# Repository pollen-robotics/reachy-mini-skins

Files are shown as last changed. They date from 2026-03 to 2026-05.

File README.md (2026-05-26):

# 🎨 Reachy Mini Skins

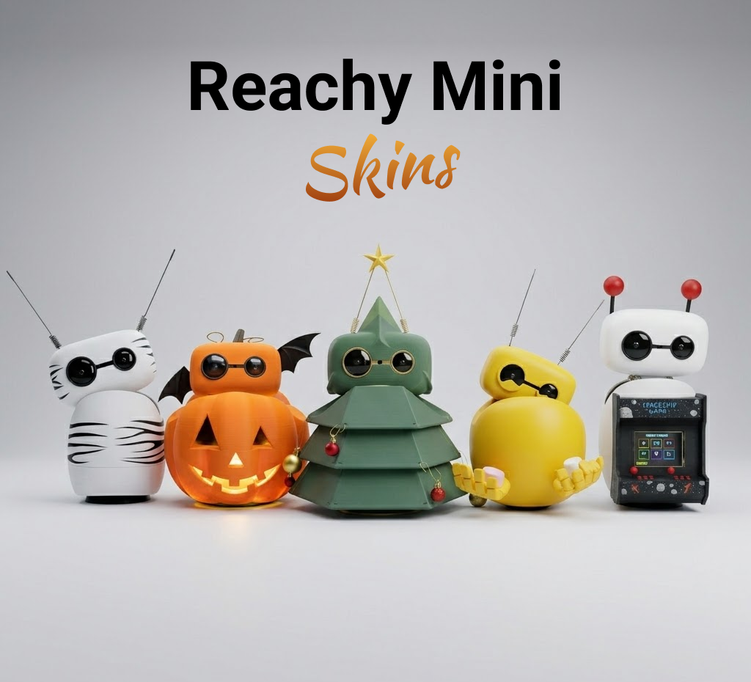
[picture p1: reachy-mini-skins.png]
reachy-mini-skins


This repository gathers the official Reachy Mini skins created by Pollen Robotics, showcasing playful, seasonal, refined, and expressive ways to bring personality to your robot.

From playful and seasonal designs to more refined and expressive looks, these official skins showcase different ways to bring personality to Reachy Mini.

Community creations are not included in this repository. They are available on the [Reachy Mini Skins Space](https://huggingface.co/spaces/pollen-robotics/reachy-mini-skins), where users can browse and submit their own designs.

<br clear="left">

## Add a new skin

1. Go to the “Submit your skin” section on the [Reachy Mini Skins Space](https://huggingface.co/spaces/pollen-robotics/reachy-mini-skins)
2. Fill out the form with:
- a name
- a short description (90 max)
- a few tags
- a clean, sharp photo
- a link to the Git repository or any other page containing the instructions and downloadable files
- Click Submit.
This will automatically create a pull request for the Pollen Robotics team to review.
3. Once approved, your skin will appear in the community skin gallery.

## Important note

Some shared files may be community bonus content released for fun and experimentation.

They are not meant to replace the normal product support workflow. If something is wrong with a community STL or experimental skin file, please **do not use the standard support/debug channels for that** unless the issue concerns the robot itself.

# ⚖️ License
This work is licensed under a
[Creative Commons Attribution-NonCommercial 4.0 International License](https://creativecommons.org/licenses/by-nc/4.0/legalcode.en).

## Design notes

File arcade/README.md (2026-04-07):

## 🕹️ Arcade Skin

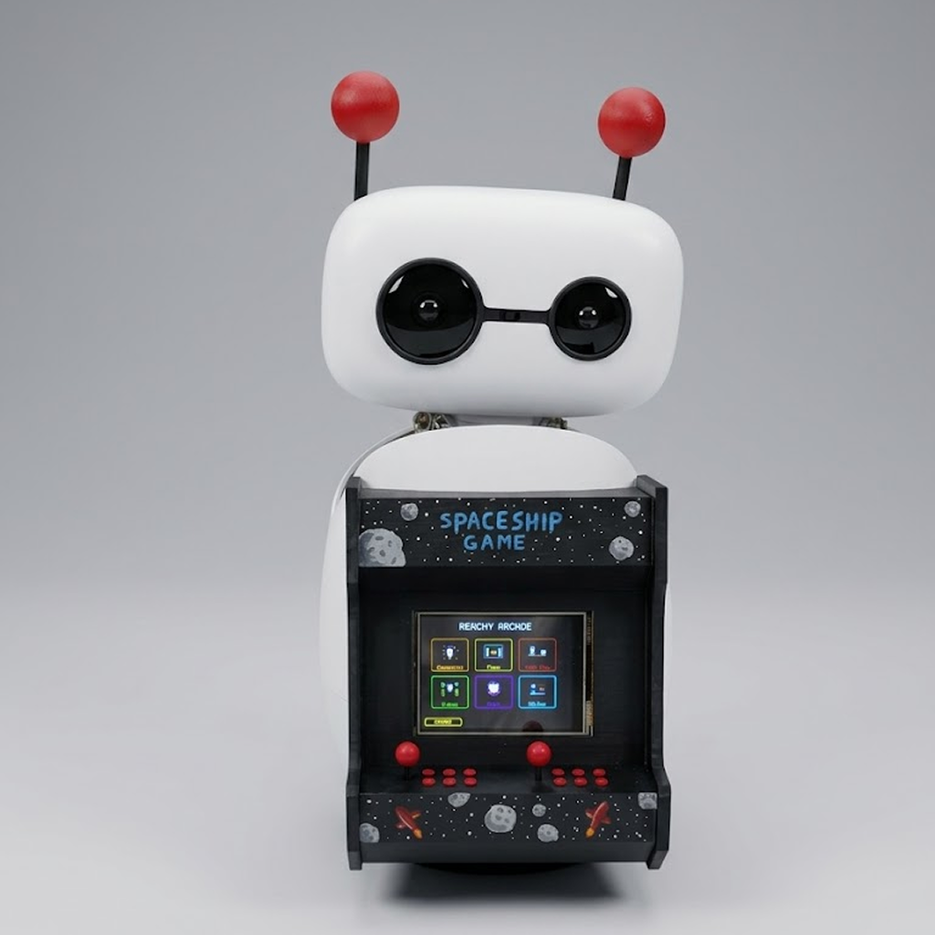
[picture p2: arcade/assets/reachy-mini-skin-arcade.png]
Reachy Mini arcade


A retro arcade cabinet skin for Reachy Mini, featuring a 3D-printed arcade structure and an added screen.

The screen is connected directly to a PC, bringing the arcade effect to life. The antennas were also 3D printed to match the overall design.

<br clear="left">

---

### Steps to make it :

<details>
<summary><span style="font-size:1.2em"><b>BOM</b></span></summary>

#### 3D Printing
- PLA filament

#### Electronics
- ESP32-2432S028 (Cheap Yellow Display)
- Right-angle USB cable:
  - **Reachy Mini Wireless:** USB-C to USB-C (must be USB-C on both ends)
  - **Reachy Mini Lite:** USB-A to USB-C or USB-C to USB-C

#### Assembly
- Hot glue gun
- 4x M2 5mm screws for the screen

</details>

<details>
<summary><span style="font-size:1.2em"><b>3D Printing</b></span></summary>

STL and STEP files are available in the [`3d-models/`](3d-models/) folder.

| Part | File | Quantity | Supports |
|---|---|---|---|
| Arcade body | `reachy_mini_arcade.stl` / `reachy_mini_arcade.step` | 1x | Yes |
| Antenna | `antenna.stl` | 2x | Yes |

**Print settings:** Standard PLA settings. Supports are needed for both parts.

#### Customization

You can paint the parts or add stickers to personalize your arcade skin however you like. For reference, ours is inspired by the [Spaceship Game](https://huggingface.co/spaces/apirrone/spaceship_game), a Reachy Mini app.

<p>
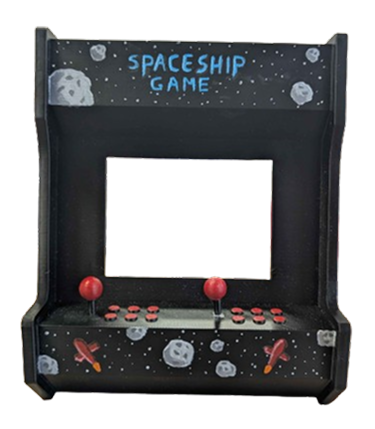
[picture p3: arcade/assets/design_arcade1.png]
Arcade design 1

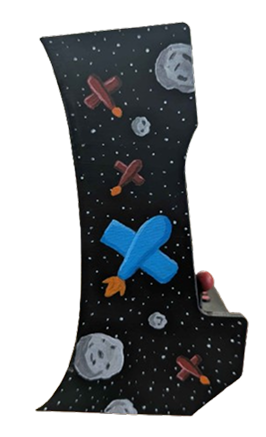
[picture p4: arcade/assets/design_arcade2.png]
Arcade design 2

</p>

</details>

<details>
<summary><span style="font-size:1.2em"><b>Electronics</b></span></summary>

The arcade screen uses an **ESP32-2432S028** (aka "Cheap Yellow Display" / CYD). The firmware source code is in the [`code/`](code/) folder — it's a PlatformIO project.

#### Flashing the firmware

1. Connect the ESP32 to your PC via USB
2. Clone this repository:
   ```bash
   git clone https://github.com/pollen-robotics/reachy-mini-skins.git
   ```

3. **Upload the code:**

<details>
<summary><b>From the command line</b></summary>

- Install PlatformIO CLI (a virtual environment is recommended):
   ```bash
   pip install platformio
   ```
- Navigate to the firmware folder and upload:

   **Linux / macOS:**
   ```bash
   cd reachy-mini-skins/arcade/code
   pio run -e arcade --target upload
   ```

   **Windows:**
   ```powershell
   cd reachy-mini-skins\arcade\code
   pio run -e arcade --target upload
   ```

</details>

<details>
<summary><b>From VS Code</b></summary>

- Install [VS Code](https://code.visualstudio.com/) and the [PlatformIO extension](https://marketplace.visualstudio.com/items?itemName=platformio.platformio-ide)
- Open the `reachy-mini-skins/arcade/code` folder in VS Code
- Click the PlatformIO icon in the sidebar:

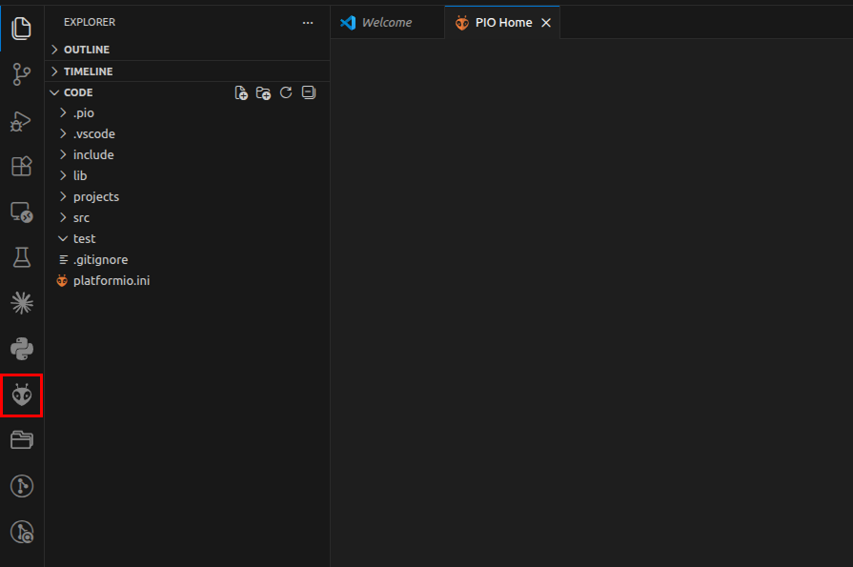
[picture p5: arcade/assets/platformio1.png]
PlatformIO icon
  

- Click the **Upload** button at the bottom of VS Code:

  PlatformIO upload button

</details>

Once uploaded, the screen should power on and display the arcade menu.

</details>

<details>
<summary><span style="font-size:1.2em"><b>Assembly</b></span></summary>

1. **Prepare the parts**
   - Make sure all printed parts are ready
   - Remove supports and clean up the surfaces
   - Make sure you have flashed the firmware onto the ESP32 (see Electronics section above)

2. **Replace the antennas**
   - Unscrew the stock antenna screws on Reachy Mini
   - Replace them with the 3D-printed antennas and screw them back in

3. **Mount the screen**
   - Screw the screen onto the arcade body (4x M2 5mm screws)
   - Optionally, glue the screen cable in place to prevent it from moving around

4. **Attach the body skin**
   - Place the arcade body shell onto Reachy Mini
   - For now there is no snap or screw attachment — simply use a hot glue gun to secure the shell to the robot

5. **Connect the arcade**
   - **Reachy Mini Wireless:** plug the USB-C cable into the USB-C port on the back of the robot
   - **Reachy Mini Lite:** plug the USB cable into your PC

</details>

---

### Ready to use the arcade?

1. Turn on Reachy Mini
2. Make sure the arcade screen is connected:
   - **Wireless:** to the USB-C port on the back of the robot
   - **Lite:** to your PC
3. Download and launch the [Arcade app](https://huggingface.co/spaces/cdeplanne/arcade) from the Reachy Mini desktop app
4. On the landing page, choose **"With physical arcade"**
5. The app will automatically scan USB ports and detect the ESP32 — once detected, you're ready to play!

> If the arcade is not detected automatically, make sure the ESP32 is plugged in and the firmware is flashed. You can also select the port manually from the setup page.

Now all that's left is to play!

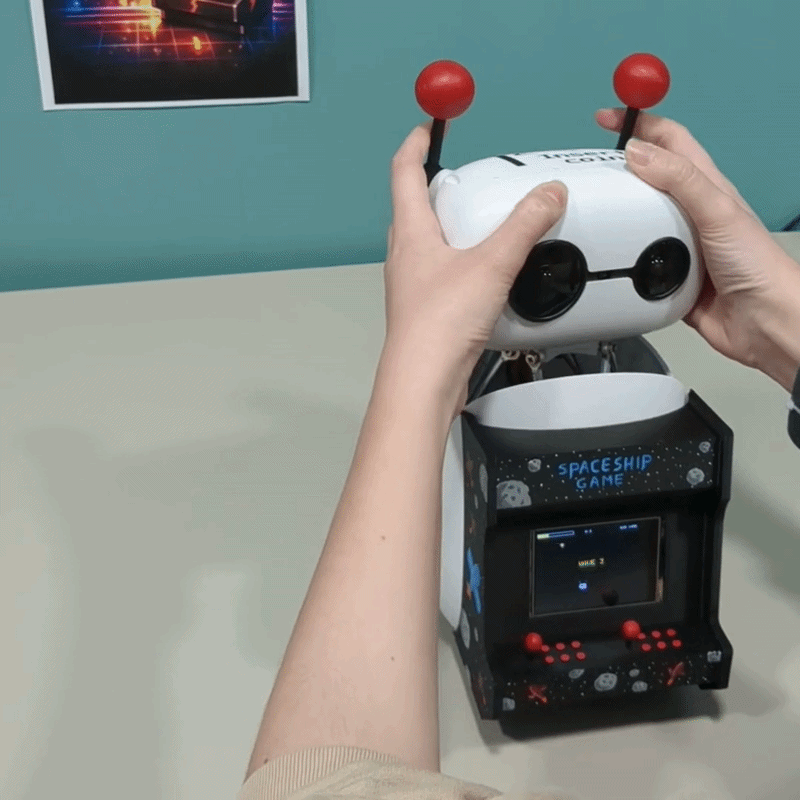
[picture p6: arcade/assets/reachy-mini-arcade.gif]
Reachy Mini Arcade demo


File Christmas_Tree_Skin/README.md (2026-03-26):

## 🎄Christmas Tree Skin

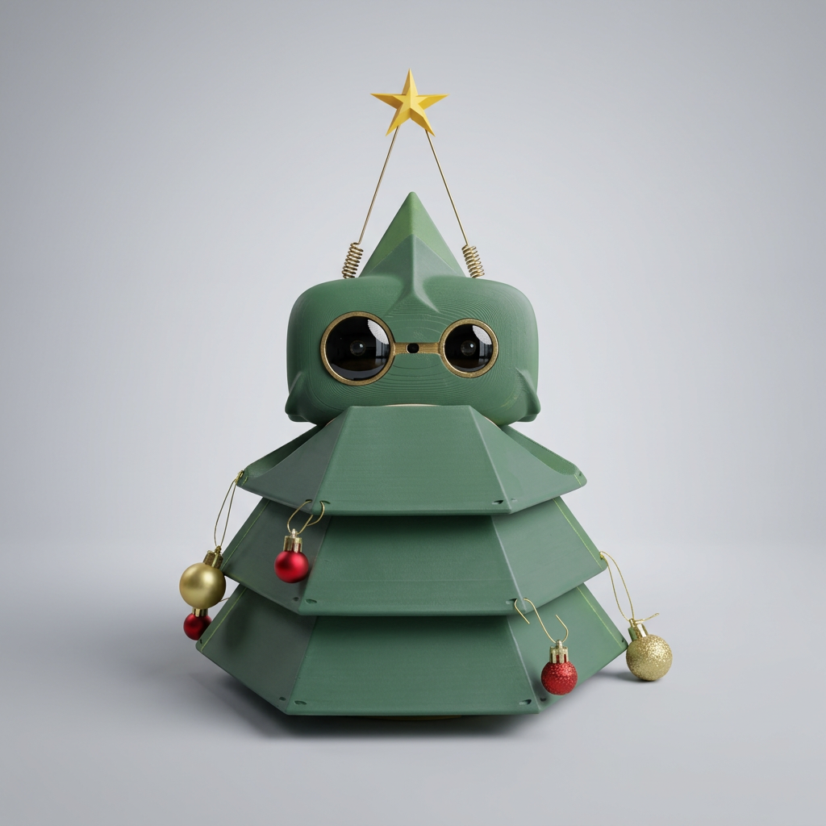
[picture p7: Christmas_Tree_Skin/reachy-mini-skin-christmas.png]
Reachy Mini Christmas tree


Give Reachy Mini a bold festive look with this shell customization. 

This skin combines 3D-printed parts, optional painting, and a magnetic star assembly for a polished final result.

<br clear="left">

### Steps to make it

1. **3D print the provided files**  
   You can print the parts directly in green filament if you want to reduce the amount of painting.  
   For reference, we printed ours in white.
   We printed the stars in golden filament.

3. **Paint the parts**  
   If you did not print them in green, you can paint them in green. For reference, we used:
   - **Color:** Pine Green
   - **Finish:** Satin  
   [Reference spray paint](https://www.bricorama.fr/p/peinture-aerosol-vert-pin-satin-400ml/3505390094488)

4. **Insert magnets and pins**  
   - Add magnets inside the stars so they align properly and form a star shape when the antennas touch. You will need 2 magnets [4mm x 3mm](https://www.amazon.fr/-/en/Wukong-Magnets-Neodymium-Printer-Project/dp/B0D31NCQNS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). You can use super glue to secure them in place.
     - Make sure to orient the magnets correctly so that they attract each other when the antennas are close. 
   - Insert pins in the holes of the body parts to allow them to snap together securely. You will need at least 4 [pins 3mm x 16mm](https://www.amazon.fr/-/en/PATIKIL-Stainless-Cylindrical-Furniture-Positioning/dp/B0DHVNX6C5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). 

5. **Assemble everything**  
   - Once all parts are printed, painted, and fitted with magnets, assemble the skin onto Reachy Mini.
   - To assemble the head, you will need 3x self tapping screws 2.5mm x 6mm.
   - The body parts should snap together with the pins
   - The star must be pressed on the antennas, make sure to align the magnets correctly so they attract each other and form a star shape.
   - Some decorative elements can be added to the body parts if you wish, such as small ornaments or tinsel.

6. **Change the antennas motors configuration** (safety)  
   - If you want to make the antennas move safely, you can [change the configuration of the antennas motors in the configuration file](https://github.com/pollen-robotics/reachy_mini/blob/1c347437881846b4ea3f293838baf11323c3e536/src/reachy_mini/assets/config/hardware_config.yaml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), especially the limits of the motors position, to avoid any collision between the stars/antennas and the body.

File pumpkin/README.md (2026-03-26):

## 🎃 Halloween Pumpkin skin aka "Reachy-trouille"

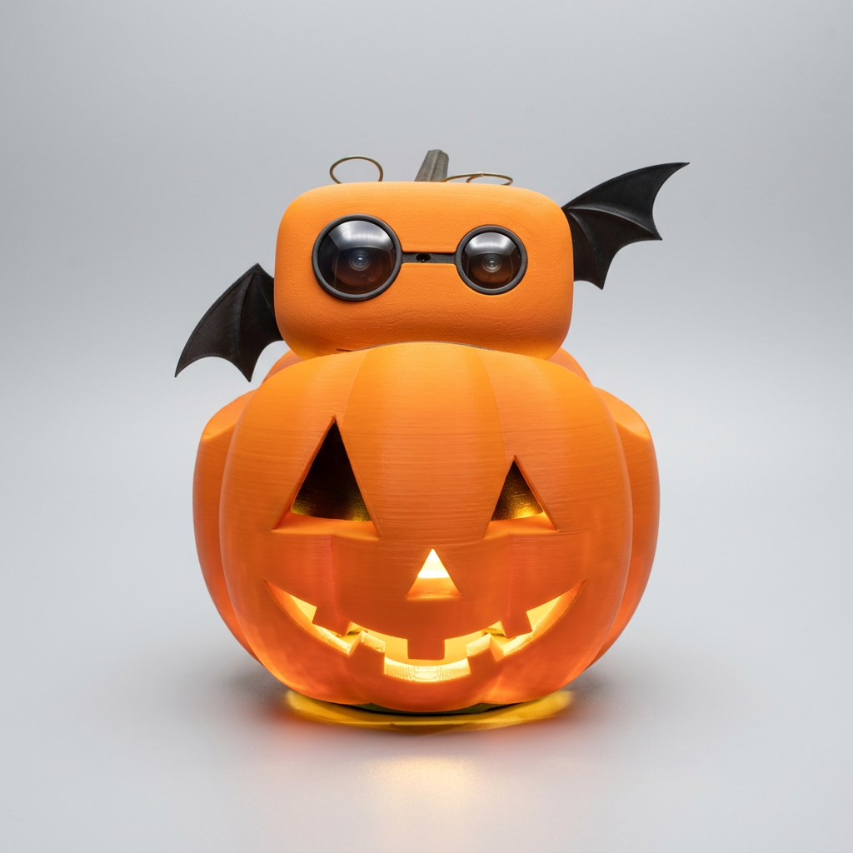
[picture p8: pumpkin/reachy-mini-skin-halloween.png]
Reachy Mini pumpkin for Halloween


A spooky jack-o’-lantern skin created for Halloween events, designed to give Reachy Mini a festive look. 

The body features an additional 3D-printed shell painted in orange, while the antennas were also 3D printed to form small bat wings. On the skin we made, we directly painted the head parts. But a thin 3D-printed cover can be added over the robot’s head as well, so there is no need to paint directly on the injected plastic shell.

<br clear="left">

### Steps to make it

1. **3D print the provided files**: Pumpkin, bat wings, top of the pumpkin

   You can print the parts directly in orange filament for the pumpkin, green filament for the top of the pumpkin, black filament for the bat wings, if you want to reduce the amount of painting.
   For reference, we printed ours in white.
   
3. **Paint the parts**

   If you did not print them in colors, you can paint them with spray paint. For reference, we used:

   - Pumkin and robot's face: Orange Cuivre RAL 2001 mat ([ref](https://www.bricorama.fr/p/peinture-aerosol-orange-cuivre-mat-400ml/3505390094594))
   - Top of the pumpkin: Pine Green RAL 6028 Satin ([ref](https://www.bricorama.fr/p/peinture-aerosol-vert-pin-satin-400ml/3505390094488))
   - Bat wings: Black Mat ([ref](https://www.leroymerlin.fr/produits/bombe-de-peinture-relook-tout-maison-deco-noir-mat-400-ml-70198814.html))
   - The result can be improved by painting in black or putting a black sticker/thin shell on the body surface, under the pumpkin skin, to hide the robot's original white face and make the pumpkin face stand out more.

5. **Insert pins**  
   - Insert pins in the holes of the body parts to allow them to snap together securely. You will need at least 4 [pins 3mm x 16mm](https://www.amazon.fr/-/en/PATIKIL-Stainless-Cylindrical-Furniture-Positioning/dp/B0DHVNX6C5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). 

6. **Assemble everything**  
   - Once all parts are printed, painted, and fitted with pins, assemble the skin onto Reachy Mini.
   - If you printed a cover for the head, you can stick it with thin double-sided tape.
   - The body parts should snap together with the pins
   - There is a channel inside the body shell to pass a string of light LEDs if you want to add some spooky lighting effects to your pumpkin skin. You can use a small battery pack to power the LEDs and hide it inside the body shell as well. We glued it to the inside of the pumpkin shell with glue gun, under the eyes and the mouth, to create a glowing effect. Make sure to leave the switch accessible so you can turn the lights on and off easily.

7. **Change the antennas motors configuration** (safety)  
   - If you want to make the bat wings move safely, you can [change the configuration of the antennas motors in the configuration file](https://github.com/pollen-robotics/reachy_mini/blob/1c347437881846b4ea3f293838baf11323c3e536/src/reachy_mini/assets/config/hardware_config.yaml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), especially the limits of the motors position, to avoid any collision between the wings and the body.

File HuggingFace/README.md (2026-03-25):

## 🤗 HuggingFace skin

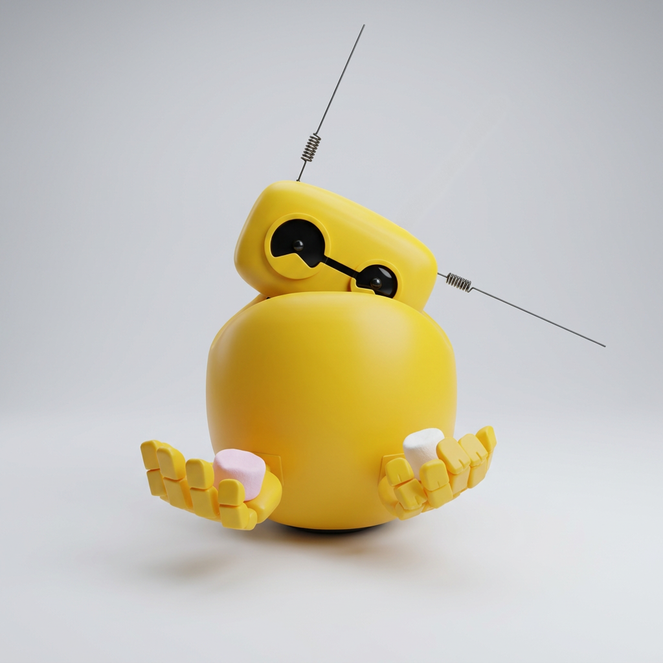
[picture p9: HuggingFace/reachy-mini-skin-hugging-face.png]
Reachy Mini Hugging Face


A cheerful yellow companion skin for Reachy Mini, featuring articulated hands designed to hold small objects and add an extra playful touch.

<br clear="left">

### How to make it

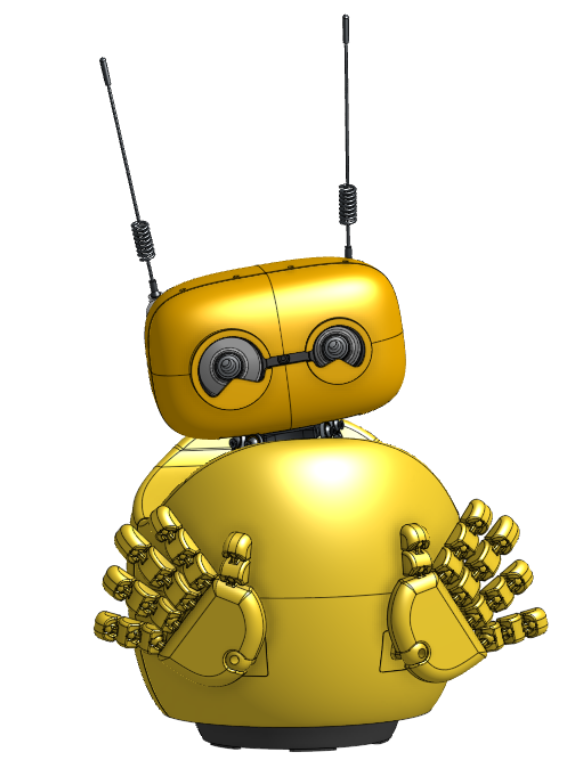
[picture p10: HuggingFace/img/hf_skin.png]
HF skin Reachy Mini HuggingFace Skin


The shell is held with 3mm pins and 5mm magnets

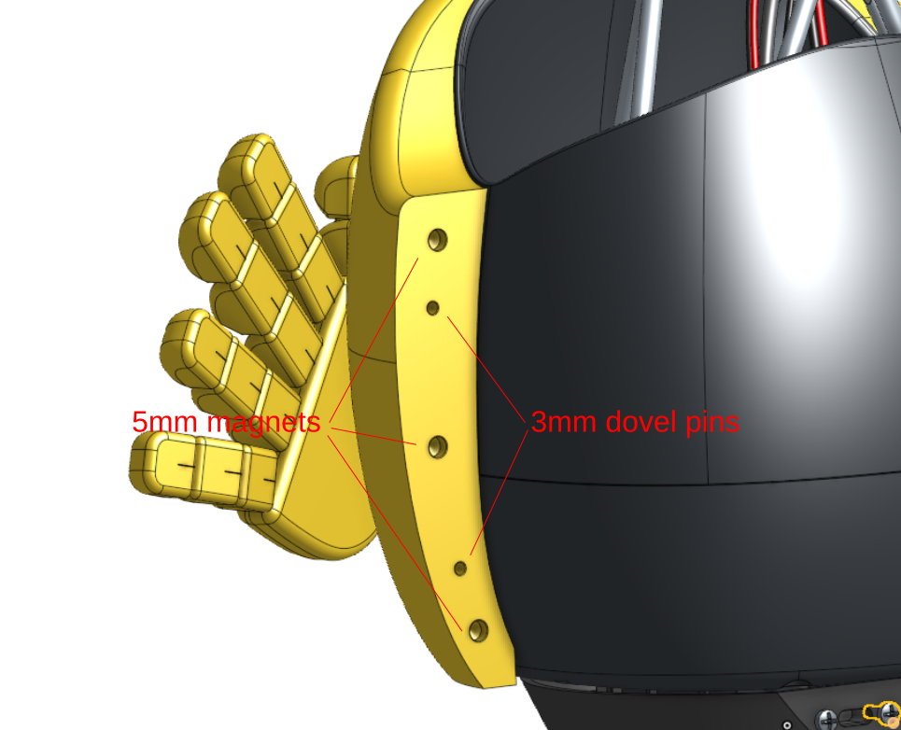
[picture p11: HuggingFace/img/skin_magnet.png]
HF skin shell Shell pin and magnet


### Eyes

Eyes can be changed in order to produce different face expressions.
They are inserted inside small grooves in the face skin. They are locked in position by glueing small tabs to the eye.

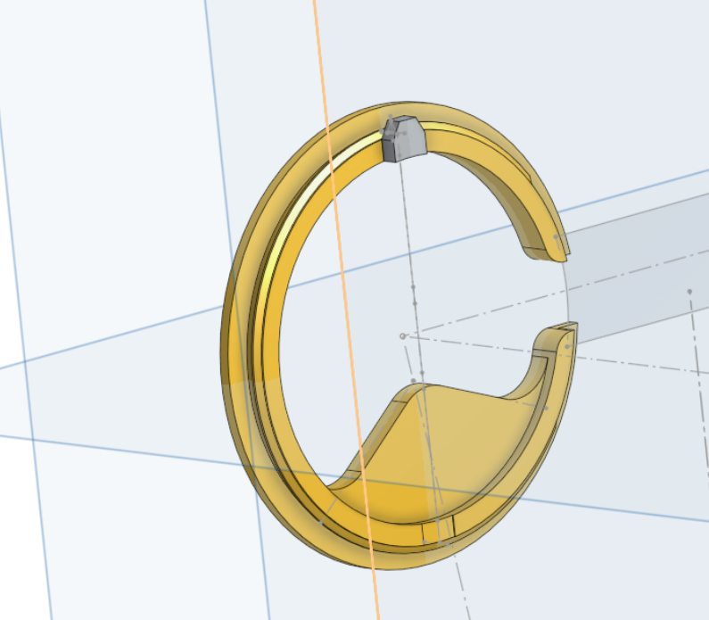
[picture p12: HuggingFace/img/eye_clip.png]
HF skin eye clip Eye clip


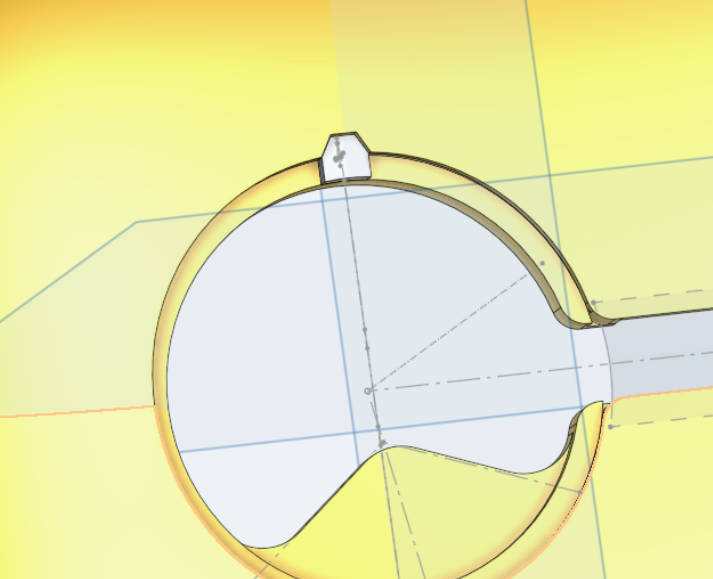
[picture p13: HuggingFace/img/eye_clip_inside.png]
HF skin eye clip inside Eye clip inside view


### Hands

Hands are articulated and fixed to the shell using two different blocks inserted in the front shell.

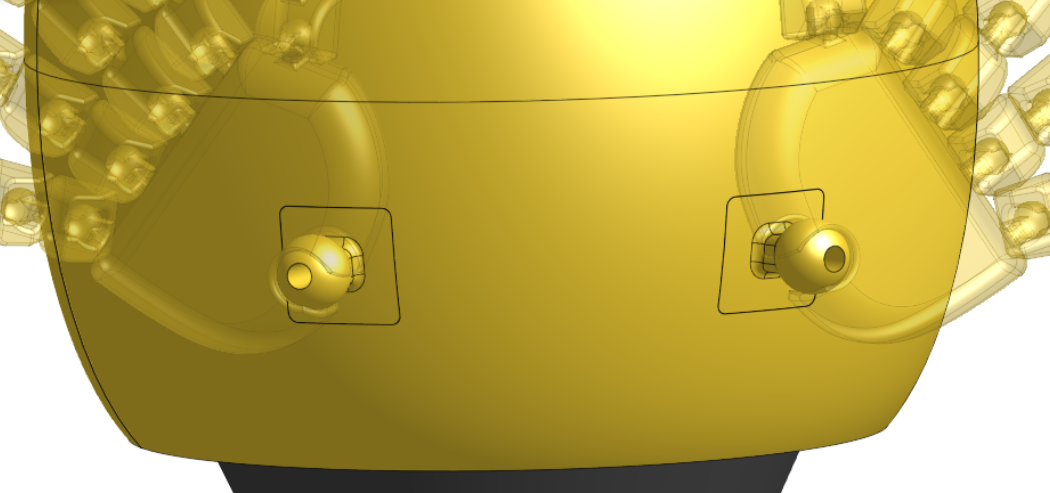
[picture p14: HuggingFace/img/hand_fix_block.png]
HF skin hand fixation blocks Hand fixation blocks


Then for both the left and right hand, phalanges are reused across fingers

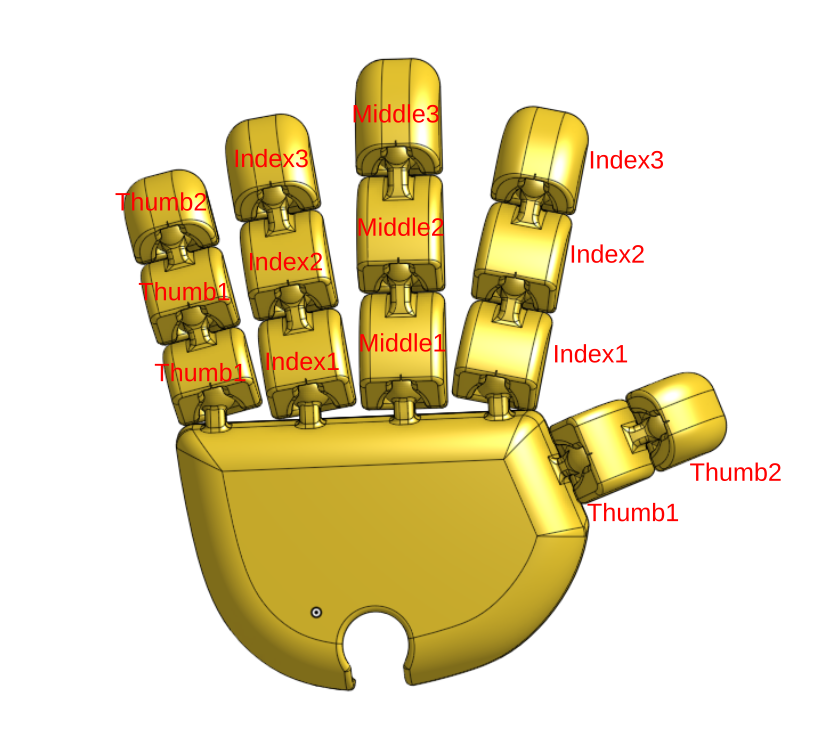
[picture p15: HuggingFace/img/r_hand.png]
HF skin right hand Right hand


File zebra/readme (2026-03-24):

🦓 Zebra skin

Bring a playful zebra look to Reachy Mini with a simple sticker-based customization that lets you decorate the shell without damaging the robot.

Steps to make it

1. Print the pattern on an A4 sticker sheet
   For reference, we used this format: https://www.bruneau.fr/product/etiquette-multi-usages-avery-office-star-blanche/ST04975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

2. Cut the stripes with scissors
   Trim and shorten the stripes depending on the visual effect you want on the robot’s body or head.

3. Apply the stickers where you want
   Place the stripes on the shell in the desired areas to create your own zebra style.

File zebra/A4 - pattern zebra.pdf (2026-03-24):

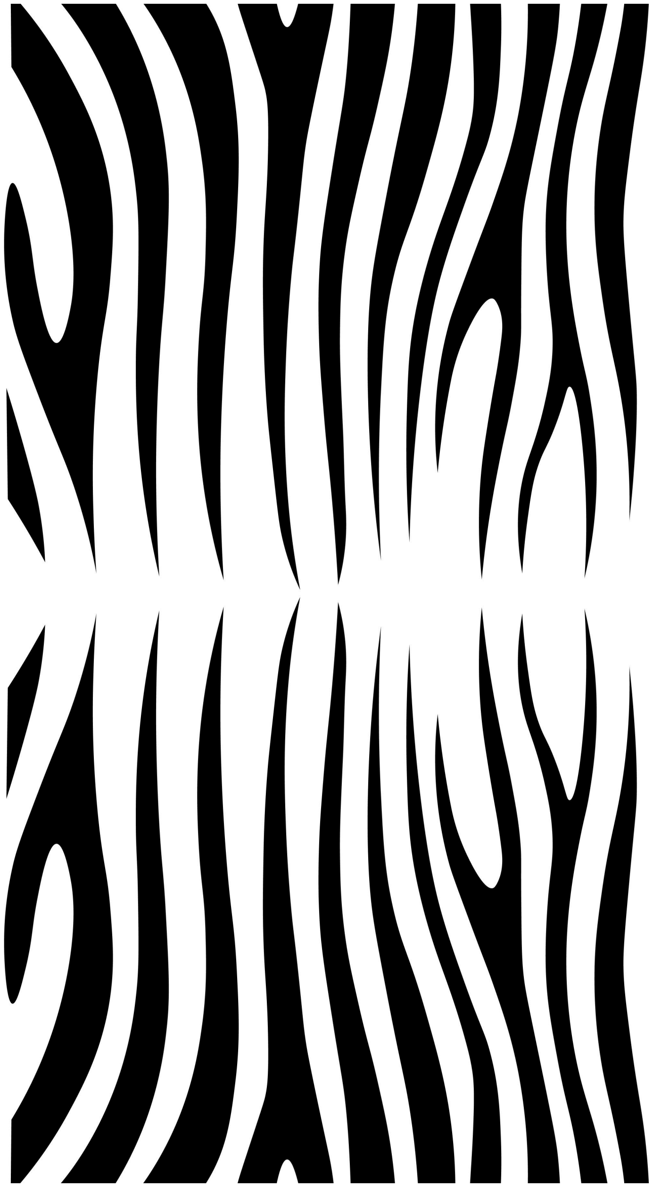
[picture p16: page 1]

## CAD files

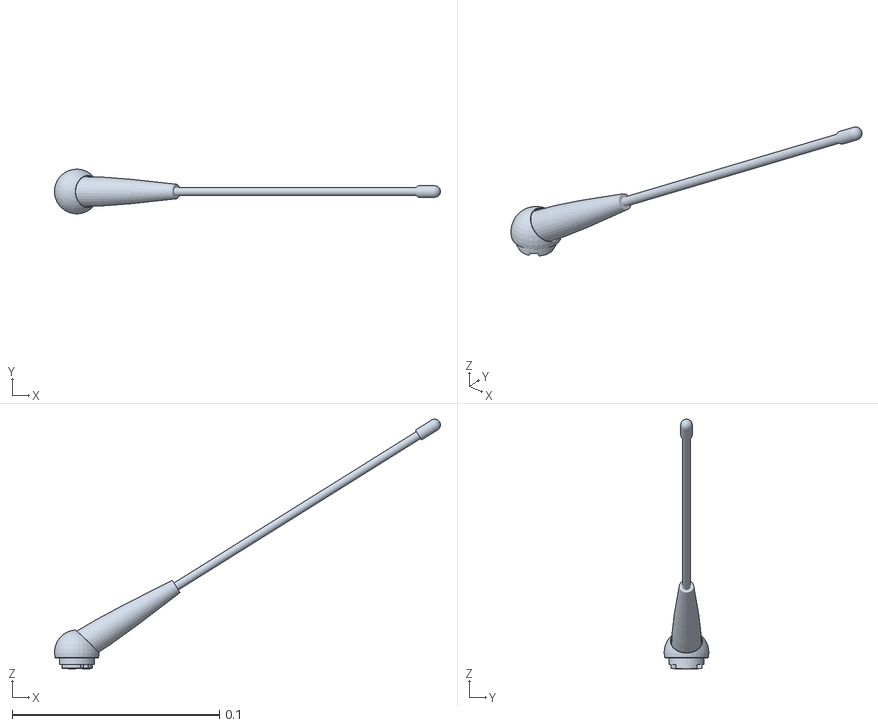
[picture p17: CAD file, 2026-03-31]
arcade/3d-models/antenna.stl
0.186 x 0.0216 x 0.121

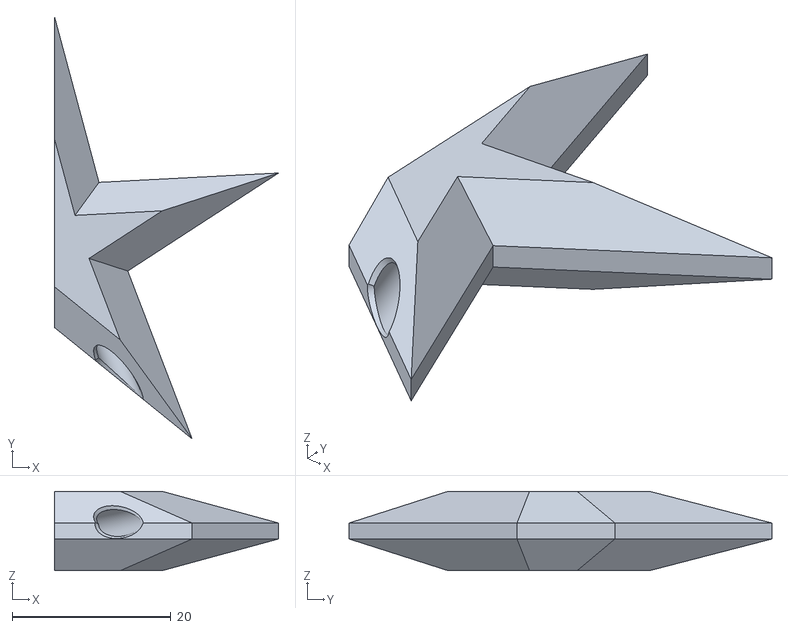
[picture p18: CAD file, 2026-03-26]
Christmas_Tree_Skin/Christmas Tree Skin - Star_L.stl
28.3 x 53.3 x 10.0

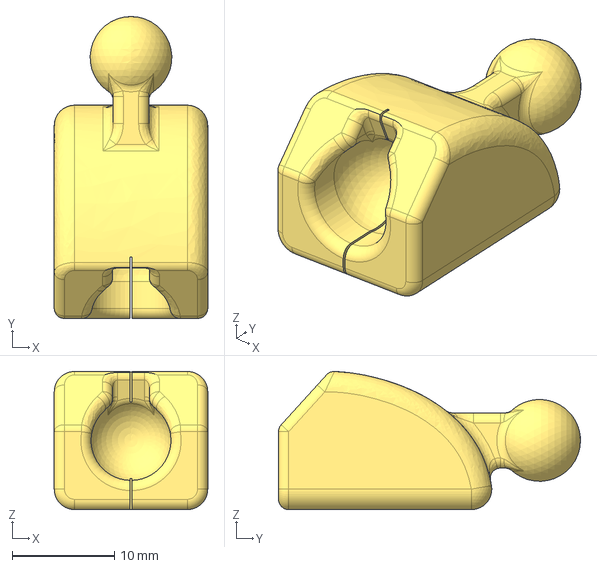
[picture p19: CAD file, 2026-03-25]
HuggingFace/step/hands/middle1.step
15.0 x 29.5 x 13.5 mm

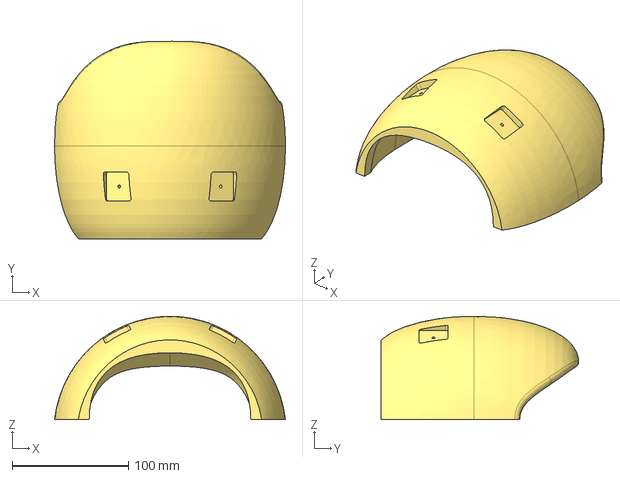
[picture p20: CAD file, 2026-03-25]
HuggingFace/step/RM_HF - hf_front.step
198.8 x 170.0 x 89.1 mm

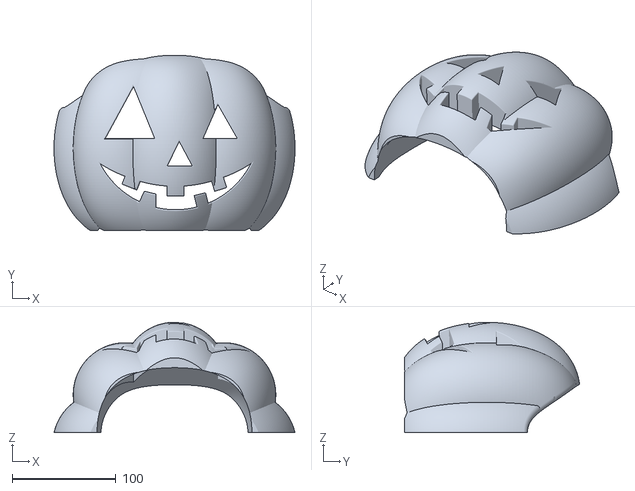
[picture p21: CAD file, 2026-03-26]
pumpkin/Pumpkin_front.stl
232.1 x 168.8 x 106.3

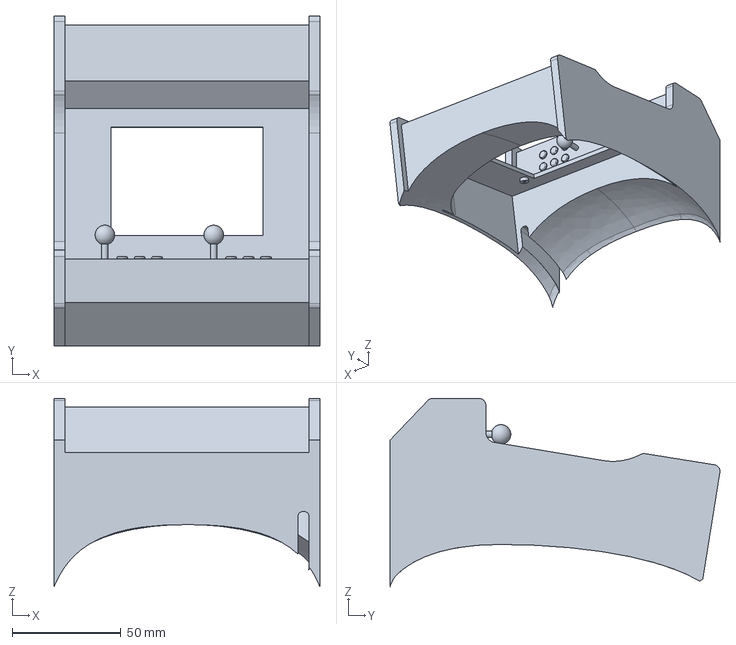
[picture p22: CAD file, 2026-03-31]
arcade/3d-models/reachy_mini_arcade.step
122.0 x 151.5 x 86.4 mm

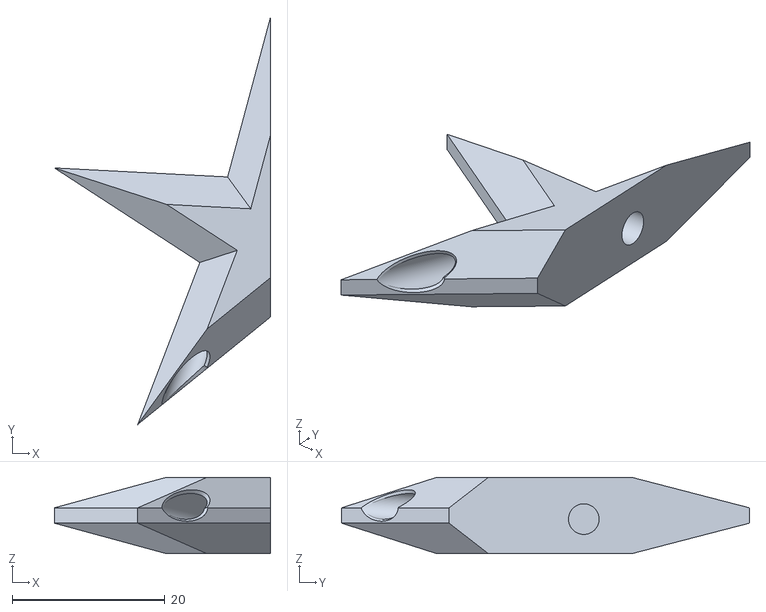
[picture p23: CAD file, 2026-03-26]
Christmas_Tree_Skin/Christmas Tree Skin - Star_R.stl
28.3 x 53.3 x 10.0

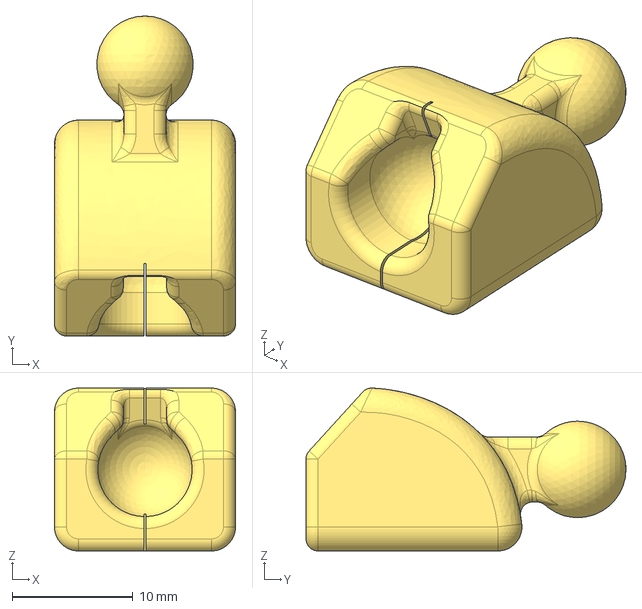
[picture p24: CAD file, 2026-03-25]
HuggingFace/step/hands/index1.step
15.0 x 26.5 x 13.5 mm

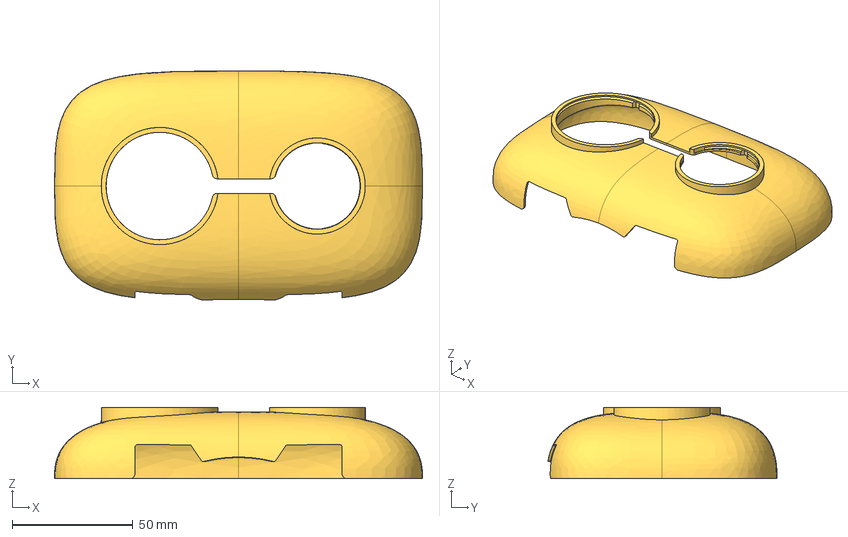
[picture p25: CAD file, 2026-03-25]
HuggingFace/step/RM_HF - front_skin2.step
152.2 x 94.8 x 29.5 mm

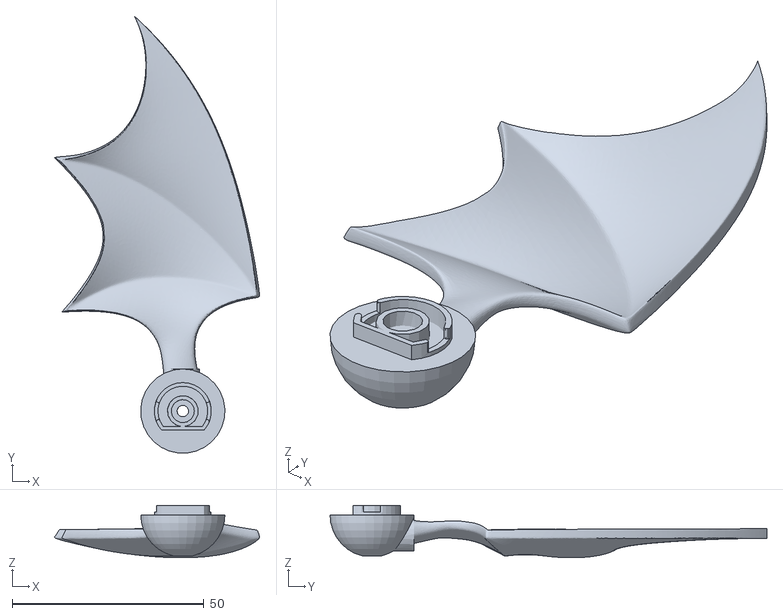
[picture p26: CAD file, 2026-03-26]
pumpkin/R_bat_ear_low.stl
53.5 x 114.1 x 13.7

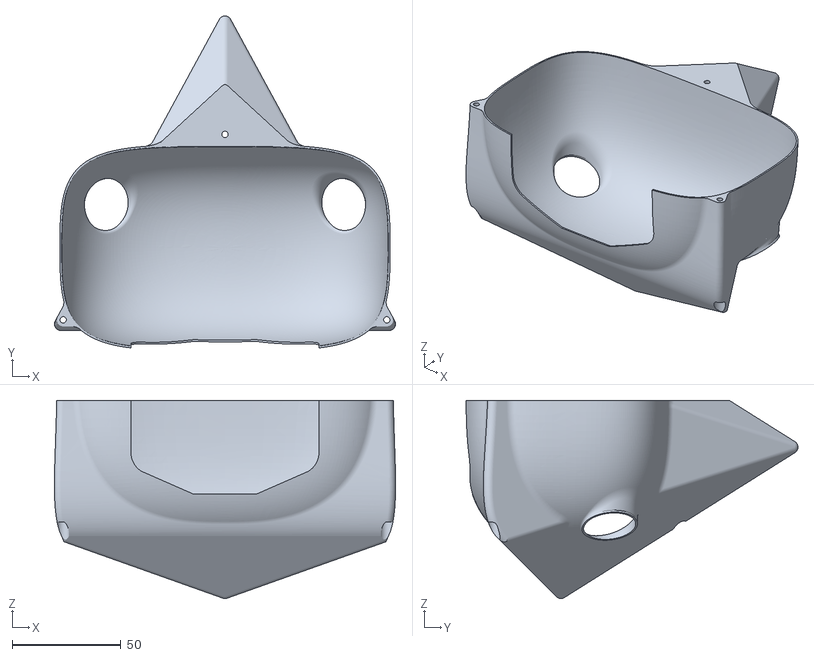
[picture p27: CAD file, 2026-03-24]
Christmas_Tree_Skin/Christmas Tree Skin - Tree_top_back.stl
157.0 x 152.8 x 91.2

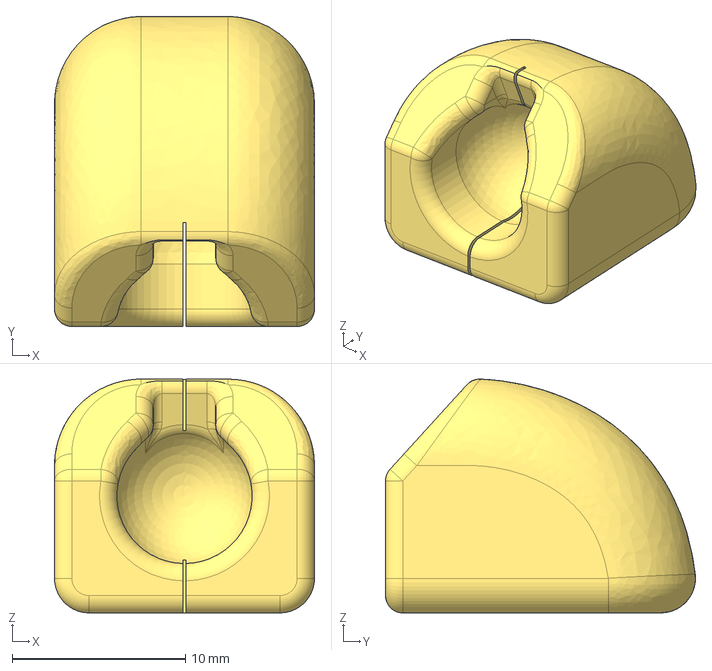
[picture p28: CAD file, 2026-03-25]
HuggingFace/step/hands/index3.step
15.0 x 17.9 x 13.5 mm

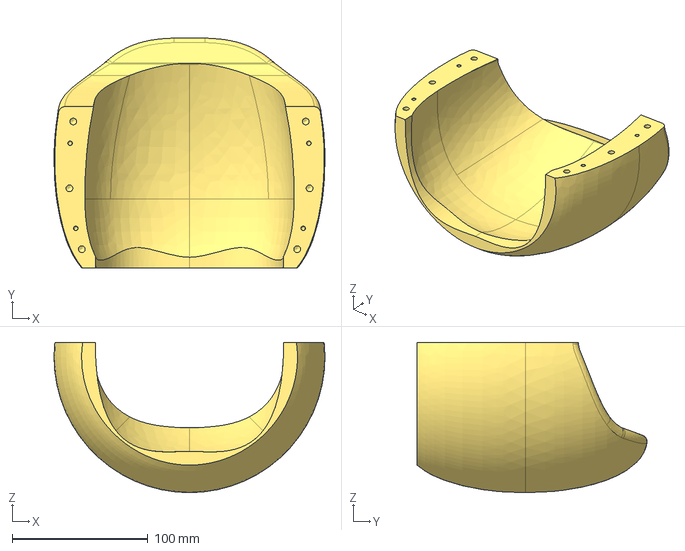
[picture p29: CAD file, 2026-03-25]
HuggingFace/step/RM_HF - hf_back.step
200.0 x 169.8 x 110.9 mm

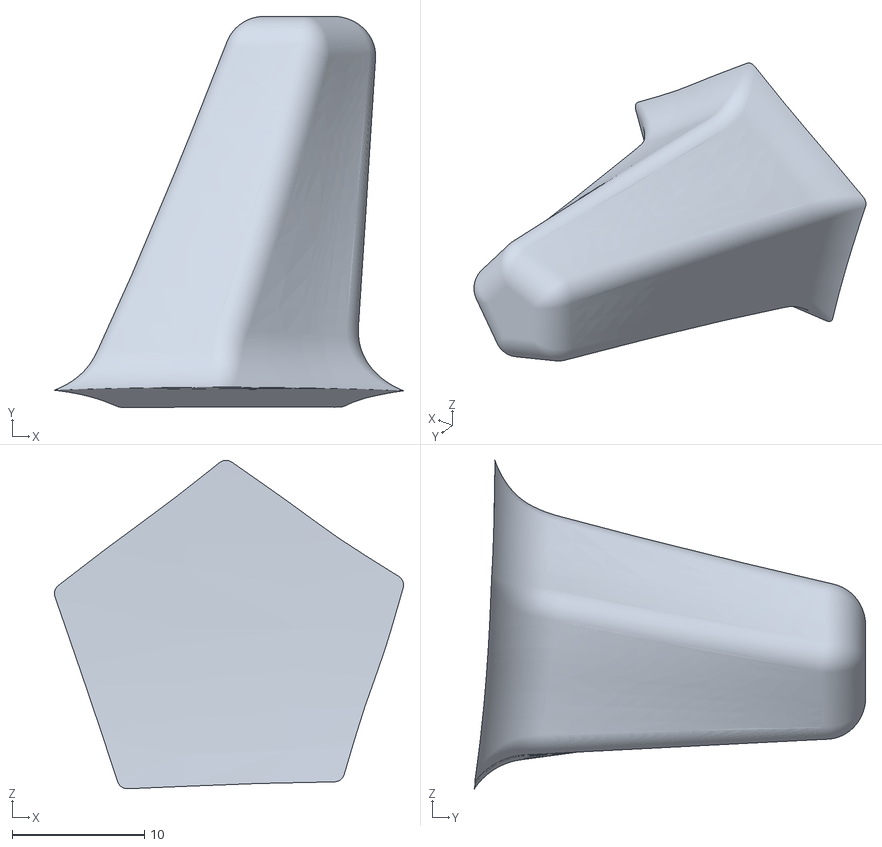
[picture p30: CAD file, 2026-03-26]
pumpkin/Pumpkin_tail.stl
26.4 x 29.6 x 24.8

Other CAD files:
Christmas_Tree_Skin/Christmas Tree Skin - Tree_top_front.stl
HuggingFace/step/hands/thumb1.step
HuggingFace/step/RM_HF - Back Skin.step
pumpkin/Pumpkin_back.stl
Christmas_Tree_Skin/Christmas Tree Skin - Tree_base_back.stl
Christmas_Tree_Skin/Christmas Tree Skin - Tree_base_front.stl
HuggingFace/step/RM_HF - bigeye.step
HuggingFace/step/RM_HF - clip.step
HuggingFace/step/RM_HF - fix_block_l.step
HuggingFace/step/RM_HF - fix_block_r.step
HuggingFace/step/RM_HF - smalleye.step
HuggingFace/step/RM_HF_skin_all_in_one.step
HuggingFace/step/hands/index2.step
HuggingFace/step/hands/l_hand.step
HuggingFace/step/hands/middle2.step
HuggingFace/step/hands/middle3.step
HuggingFace/step/hands/r_hand.step
HuggingFace/step/hands/thumb2.step
HuggingFace/stl/RM_HF - Back Skin.stl
HuggingFace/stl/RM_HF - bigeye.stl
HuggingFace/stl/RM_HF - clip.stl
HuggingFace/stl/RM_HF - fix_block_l.stl
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

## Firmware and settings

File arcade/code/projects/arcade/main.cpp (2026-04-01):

#include <Arduino.h>
#include <TFT_eSPI.h>
#include <SPI.h>
#include <XPT2046_Touchscreen.h>
#include <ArduinoJson.h>
#include "game.h"
#include "scores.h"
#include "sound.h"
#include "name_entry.h"
#include "menu.h"
#include "games/spaceship.h"
#include "games/pong.h"
#include "games/dino.h"
#include "games/flappy.h"
#include "games/boss.h"
#include "games/rhythm.h"

#define SCREEN_W 320
#define SCREEN_H 240
#define SERIAL_BAUD 2000000

// Touch - exactement comme le calibrate
#define XPT_CLK  25
#define XPT_MISO 39
#define XPT_MOSI 32
#define XPT_CS   33
#define XPT_IRQ  36

TFT_eSPI tft = TFT_eSPI();
TFT_eSprite fb = TFT_eSprite(&tft);
SPIClass touchSPI = SPIClass(VSPI);
XPT2046_Touchscreen ts(XPT_CS, XPT_IRQ);

Menu menu;
ScoreManager scoreMgr;
NameEntry nameEntry;
SensorData sensor;
TouchData touch;

Game *currentGame = nullptr;
SpaceshipGame spaceshipGame;
PongGame pongGame;
DinoGame dinoGame;
FlappyGame flappyGame;
BossGame bossGame;
RhythmGame rhythmGame;

unsigned long lastFrame = 0;
unsigned long lastTouchTime = 0;
bool lastLeaderboardState = false;
#define TOUCH_DEBOUNCE 300

Game* createSpaceship() { return &spaceshipGame; }
Game* createPong() { return &pongGame; }
Game* createDino() { return &dinoGame; }
Game* createFlappy() { return &flappyGame; }
Game* createBoss() { return &bossGame; }
Game* createRhythm() { return &rhythmGame; }

// Serial input
String serialBuf;
void readSerial() {
    while (Serial.available()) {
        char c = Serial.read();
        if (c == '\n') {
            JsonDocument doc;
            if (deserializeJson(doc, serialBuf) == DeserializationError::Ok) {
                // Sensor data from bridge
                if (doc.containsKey("roll")) {
                    sensor.rawRoll  = doc["roll"]  | 0.0f;
                    sensor.rawPitch = doc["pitch"] | 0.0f;
                    sensor.rawYaw   = doc["yaw"]   | 0.0f;
                    sensor.applyCalibration();
                    sensor.fireLeft  = doc["fire_left"]  | false;
                    sensor.fireRight = doc["fire_right"] | false;
                }
                // Score sync from bridge (full or single update)
                if (doc.containsKey("scores_sync")) {
                    JsonArray arr = doc["scores_sync"].as<JsonArray>();
                    for (JsonObject entry : arr) {
                        int gi = entry["game"] | -1;
                        int sc = entry["score"] | 0;
                        const char* nm = entry["name"] | "AAAA";
                        scoreMgr.receiveUpdate(gi, sc, nm);
                    }
                }
                if (doc.containsKey("score_update")) {
                    JsonObject u = doc["score_update"].as<JsonObject>();
                    int gi = u["game"] | -1;
                    int sc = u["score"] | 0;
                    const char* nm = u["name"] | "AAAA";
                    scoreMgr.receiveUpdate(gi, sc, nm);
                }
                if (doc.containsKey("ping")) {
                    Serial.println("{\"pong\":\"arcade\"}");
                }
            }
            serialBuf = "";
        } else {
            serialBuf += c;
        }
    }
}

void readTouch() {
    if (ts.touched()) {
        TS_Point p = ts.getPoint();
        touch.rawX = p.x;
        touch.rawY = p.y;
        touch.x = map(p.x, 430, 3570, 0, 319);
        touch.y = map(p.y, 500, 3550, 0, 239);
        touch.x = constrain(touch.x, 0, 319);
        touch.y = constrain(touch.y, 0, 239);
        touch.touched = true;
        lastTouchTime = millis();
    } else if (millis() - lastTouchTime > 150) {
        touch.touched = false;
    }
}

void setup() {
    Serial.begin(SERIAL_BAUD);

    pinMode(21, OUTPUT);
    digitalWrite(21, HIGH);

    // TFT d'abord
    tft.init();
    tft.setRotation(1);
    tft.fillScreen(TFT_BLACK);

    // Touch ensuite - exactement comme calibrate
    touchSPI.begin(XPT_CLK, XPT_MISO, XPT_MOSI, XPT_CS);
    ts.begin(touchSPI);
    ts.setRotation(1);

    fb.setColorDepth(8);
    if (!fb.createSprite(SCREEN_W, SCREEN_H)) {
        tft.setTextColor(TFT_RED, TFT_BLACK);
        tft.drawCentreString("SPRITE FAIL", 160, 110, 1);
        while (1) delay(1000);
    }

    scoreMgr.load();
    menu.scoreMgr = &scoreMgr;

    menu.addGame("Spaceship", 0xFD20, iconSpaceship, createSpaceship);
    menu.addGame("Pong", TFT_YELLOW, iconPong, createPong);
    menu.addGame("Duck Run", TFT_RED, iconDino, createDino);
    menu.addGame("Flappy", TFT_GREEN, iconFlappy, createFlappy);
    menu.addGame("Boss", TFT_MAGENTA, iconBoss, createBoss);
    menu.addGame("Rhythm", TFT_CYAN, iconRhythm, createRhythm);

    menu.menuEnterTime = millis();
    lastFrame = millis();
}

void loop() {
    unsigned long now = millis();
    float dt = (now - lastFrame) / 1000.0f;
    lastFrame = now;
    if (dt > 0.05f) dt = 0.05f;

    readSerial();
    readTouch();

    fb.fillSprite(TFT_BLACK);

    // --- Name entry mode ---
    if (nameEntry.active) {
        // Draw the game's game over / victory screen behind
        if (currentGame) {
            currentGame->draw(fb);
        }
        if (nameEntry.update(sensor)) {
            // Done entering name — save and return to game over screen
            scoreMgr.save(nameEntry.gameIndex, nameEntry.finalScore, nameEntry.letters);
            // Game stays in its game over state, player can then restart/exit normally
        }
        nameEntry.draw(fb);
        sensor.latch();
        fb.pushSprite(0, 0);
        return;
    }

    // --- Menu ---
    if (currentGame == nullptr) {
        menu.draw(fb);

        // Send leaderboard state changes to web
        if (menu.showLeaderboard != lastLeaderboardState) {
            lastLeaderboardState = menu.showLeaderboard;
            if (menu.showLeaderboard) {
                Serial.println("{\"show_scores\":true}");
            } else {
                Serial.println("{\"hide_scores\":true}");
            }
        }

        if (touch.touched && (now - lastTouchTime < 300)) {
            int sel = menu.handleTouch(touch);
            if (sel >= 0 && menu.entries[sel].create != nullptr) {
                touch.touched = false;
                SFX::select();
                SFX::gameStart(menu.entries[sel].name);
                sensor.calibrate();
                currentGame = menu.entries[sel].create();
                currentGame->_fb = &fb;
                currentGame->gameIndex = sel;
                currentGame->scores = &scoreMgr;
                currentGame->setup(fb);
            }
        }
    }
    // --- Game ---
    else {
        currentGame->update(dt, sensor, touch);
        currentGame->draw(fb);
        currentGame->sendState();
        sensor.latch();

        // Show name entry as soon as game over with new high score
        if (currentGame->isGameOver && !nameEntry.active) {
            int gi = currentGame->gameIndex;
            int sc = currentGame->getScore();
            if (sc > 0 && scoreMgr.isNewBest(gi, sc)) {
                nameEntry.start(gi, sc, scoreMgr.lastName);
            }
        }

        if (currentGame->wantsExit()) {
            SFX::gameStop();
            currentGame = nullptr;
            menu.menuEnterTime = millis();
        }
    }

    fb.pushSprite(0, 0);
}

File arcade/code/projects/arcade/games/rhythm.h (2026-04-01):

#pragma once
#include "../game.h"
#include "../sound.h"

#define RH_W 320
#define RH_H 240
#define RH_MAX_NOTES 32
#define RH_LANES 4
#define RH_HIT_Y 200
#define RH_HIT_WINDOW 18
#define RH_GOOD_WINDOW 30
#define RH_YAW_THRESHOLD 12.0f

// Music sync: 146 BPM, ~61.4s
#define RH_BPM 146
#define RH_BEAT_INTERVAL (60.0f / RH_BPM)  // ~0.411s
#define RH_SONG_DURATION 61.4f
#define RH_TOTAL_BEATS 149

// Note speed: how fast notes fall (pixels per frame at 60fps)
// Time for note to fall from top to hit zone = RH_HIT_Y / (noteSpeed * 60)
// We want ~1.5s travel time so player can react
#define RH_NOTE_SPEED 2.2f
#define RH_SPAWN_ADVANCE (RH_HIT_Y / (RH_NOTE_SPEED * 60.0f))  // seconds ahead to spawn

class RhythmGame : public Game {
public:
    struct Note { float y; int lane; bool active; bool hit; };
    Note notes[RH_MAX_NOTES];

    int score, combo, maxCombo;
    int hits, misses, totalNotes;
    bool exitRequested, dead, won;
    unsigned long endTime;
    unsigned long lastHitTime[RH_LANES];
    int lastHitQuality[RH_LANES];
    unsigned long qualityTime[RH_LANES];

    // Roll edge detection
    bool rollLeftActive, rollRightActive;
    bool prevRollLeft, prevRollRight;

    // Beat tracking
    float songTime;         // elapsed time in song
    int nextBeat;           // next beat index to schedule
    int beatLanes[RH_TOTAL_BEATS + 4]; // pre-generated lane for each beat (-1 = rest)
    int beatLanes2[RH_TOTAL_BEATS + 4]; // second lane for double notes (-1 = none)

    // Lane X positions
    int laneX[RH_LANES];

    void generateBeatMap() {
        // Pre-generate which lane each beat goes to
        // Patterns: 0=roll left, 1=fire left, 2=fire right, 3=roll right
        // Roll lanes are rarer, never both rolls at once
        int patterns[][2] = {
            {1, -1},  // fire left
            {2, -1},  // fire right
            {1, -1},  // fire left
            {1,  2},  // both fire
            {2, -1},  // fire right
            {1, -1},  // fire left
            {0, -1},  // roll left
            {2, -1},  // fire right
            {1, -1},  // fire left
            {2, -1},  // fire right
            {1,  2},  // both fire
            {1, -1},  // fire left
            {3, -1},  // roll right
            {2, -1},  // fire right
            {-1,-1},  // rest
            {1, -1},  // fire left
        };
        int numPatterns = 16;

        for (int i = 0; i < RH_TOTAL_BEATS + 4; i++) {
            // First 4 beats = rest (intro)
            if (i < 4) {
                beatLanes[i] = -1;
                beatLanes2[i] = -1;
                continue;
            }
            // Sometimes random
            if (random(100) < 20) {
                int r = random(100);
                if (r < 40) beatLanes[i] = 1;
                else if (r < 80) beatLanes[i] = 2;
                else if (r < 90) beatLanes[i] = 0;
                else beatLanes[i] = 3;
                beatLanes2[i] = -1;
            } else {
                int pi = (i - 4) % numPatterns;
                beatLanes[i] = patterns[pi][0];
                beatLanes2[i] = patterns[pi][1];
            }
            // Occasional rest beats (10%)
            if (random(100) < 10) {
                beatLanes[i] = -1;
                beatLanes2[i] = -1;
            }
        }
        // Count total notes for end stats
        totalNotes = 0;
        for (int i = 0; i < RH_TOTAL_BEATS; i++) {
            if (beatLanes[i] >= 0) totalNotes++;
            if (beatLanes2[i] >= 0) totalNotes++;
        }
    }

    void reset() {
        exitRequested = false;
        dead = false;
        won = false;
        endTime = 0; isGameOver = false;
        score = 0; combo = 0; maxCombo = 0;
        hits = 0; misses = 0;
        songTime = -0.5f; // small delay before music starts
        nextBeat = 0;

        rollLeftActive = false; rollRightActive = false;
        prevRollLeft = false; prevRollRight = false;

        laneX[0] = RH_W / 2 - 90;
        laneX[1] = RH_W / 2 - 30;
        laneX[2] = RH_W / 2 + 30;
        laneX[3] = RH_W / 2 + 90;

        for (int i = 0; i < RH_MAX_NOTES; i++) notes[i].active = false;
        for (int i = 0; i < RH_LANES; i++) {
            lastHitTime[i] = 0;
            lastHitQuality[i] = 0;
            qualityTime[i] = 0;
        }

        generateBeatMap();
    }

    void setup(TFT_eSprite &fb) override { reset(); }

    void update(float dt, SensorData &input, TouchData &touch) override {
        if (dead || won) {
            if ((input.fireLeft || input.fireRight) && millis() - endTime > 1500) {
                restart();
            }
            if (touch.touched && touch.y > 200) exitRequested = true;
            return;
        }

        songTime += dt;

        // Spawn notes synced to beats
        // Spawn RH_SPAWN_ADVANCE seconds ahead so note arrives at hit zone on the beat
        while (nextBeat < RH_TOTAL_BEATS) {
            float beatTime = nextBeat * RH_BEAT_INTERVAL;
            float spawnTime = beatTime - RH_SPAWN_ADVANCE;
            if (songTime >= spawnTime) {
                if (beatLanes[nextBeat] >= 0) {
                    spawnSingleNote(beatLanes[nextBeat]);
                }
                if (beatLanes2[nextBeat] >= 0) {
                    spawnSingleNote(beatLanes2[nextBeat]);
                }
                nextBeat++;
            } else {
                break;
            }
        }

        // Move notes at constant speed
        for (int i = 0; i < RH_MAX_NOTES; i++) {
            if (!notes[i].active) continue;
            notes[i].y += RH_NOTE_SPEED * dt * 60;
            // Missed
            if (notes[i].y > RH_HIT_Y + RH_GOOD_WINDOW + 10 && !notes[i].hit) {
                notes[i].active = false;
                misses++;
                combo = 0;
                lastHitQuality[notes[i].lane] = 3;
                qualityTime[notes[i].lane] = millis();
            }
            // Off screen
            if (notes[i].y > RH_H + 10) notes[i].active = false;
        }

        // Roll edge detection
        rollLeftActive = (input.roll > RH_YAW_THRESHOLD);
        rollRightActive = (input.roll < -RH_YAW_THRESHOLD);
        bool rollLeftPressed = rollLeftActive && !prevRollLeft;
        bool rollRightPressed = rollRightActive && !prevRollRight;
        prevRollLeft = rollLeftActive;
        prevRollRight = rollRightActive;

        // Check input
        if (rollLeftPressed) checkHit(0);
        if (input.fireLeftPressed()) checkHit(1);
        if (input.fireRightPressed()) checkHit(2);
        if (rollRightPressed) checkHit(3);

        // Lose: too many misses
        if (misses >= 20) {
            dead = true;
            endTime = millis(); isGameOver = true;
            SFX::die();
            SFX::gameStop();
        }
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

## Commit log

2026-03-24 Christmas tree files
    [Christmas Tree Skin - Star_L.stl, Christmas Tree Skin - Star_R.stl, Christmas Tree Skin - Tree_base_back.stl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]
2026-03-25 add files for HF skin
    [RM_HF - Back Skin.step, RM_HF - Back Skin.stl, RM_HF - bigeye.step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]
2026-03-25 Pumpkin and arcade files added
2026-03-26 Update Christmas Tree
    [Christmas Tree Skin - Star_L.stl, Christmas Tree Skin - Star_R.stl]
2026-03-26 Pumpkin update
    [L_bat_ear_low.stl, Pumpkin_back.stl, Pumpkin_front.stl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]
2026-03-26 Add links to pins and magnets
2026-03-31 Add arcade skin README and 3D model files
    [antenna.stl, reachy_mini_arcade.step, reachy_mini_arcade.stl]
2026-04-07 Update arcade: M2 screws, Wireless/Lite variants, fix cross-platform upload
